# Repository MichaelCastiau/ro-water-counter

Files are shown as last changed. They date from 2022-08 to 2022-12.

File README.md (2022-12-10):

# RO Water Counter
 

This repository contains the source code and hardware schematics for a Reverse Osmosis water counter device, based on an ESP32 module. The device allows for setting an amount of needed liters of water an will swich on/off the RO system automatically. When the amount of liters needed has been reached, the ESP32 module is programmed to interact with a webhook to send a notification to your smartphone.

It interfaces with a high-precision water flow sensor with a K-factor of 20.



## Flashing

```shell
python -m esptool  --port /dev/tty.usbserial-1420 --chip esp32 write_flash 0x00010000 .pio/build/esp32/firmware.bin
```
### Bootloader

The ESP32 requires a second stage bootloader that will read the partition table and boot the corresponding app.
The booloader is located in the `bootloader.bin` file and should be flashed at address 0x1000 in the flash.

```shell
python -m esptool  --port /dev/tty.usbmodem14301 --chip esp32 write_flash 0x1000 bootloader.bin
```

### Partition Table

This project utilises a custom partition table to make enough room for OTA updates.
The partition definitions can be found in `partitions.csv` file. The partition table should be flashed
at address 0x8000 in  the flash after building the project with PlatformIO.

```shell
python -m esptool  --port /dev/tty.usbmodem14301 --chip esp32 write_flash 0x8000 .pio/build/default/partitions.bin
```

### Application

The application itself should be flashed at address 0x10000 (or 0x210000 if using OTA), corresponding to the address defined in the bootloader table.

```shell
python -m esptool  --port /dev/tty.usbmodem14301 --chip esp32 write_flash 0x10000 .pio/build/default/firmware.bin
```

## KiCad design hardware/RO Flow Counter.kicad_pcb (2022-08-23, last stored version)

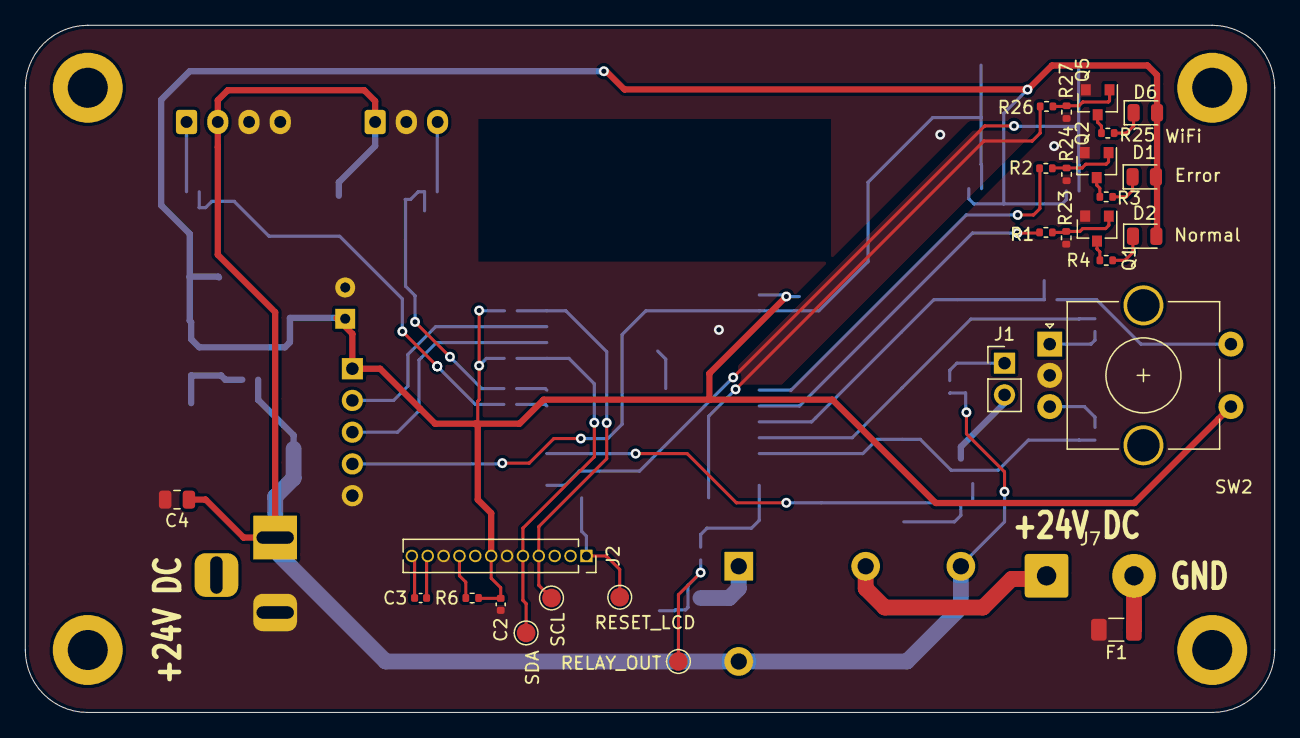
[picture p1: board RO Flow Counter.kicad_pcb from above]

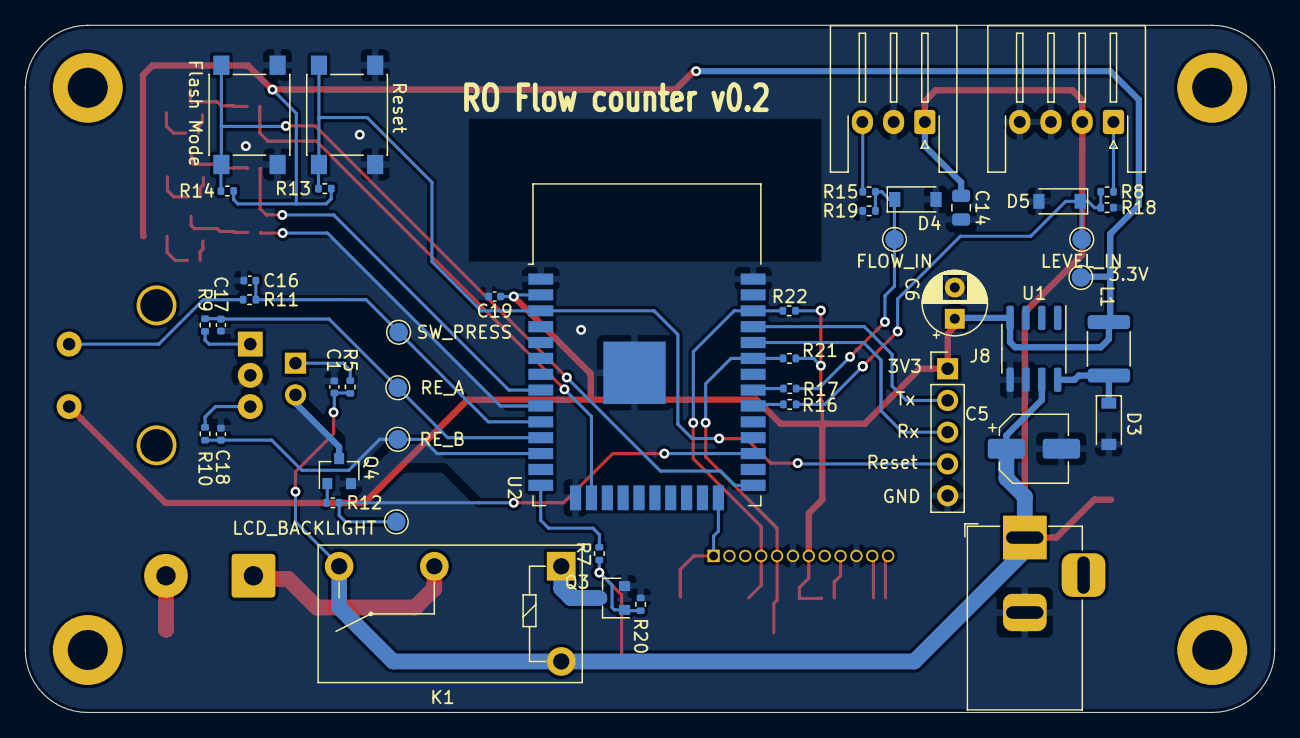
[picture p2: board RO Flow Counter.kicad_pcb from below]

Board: 2 copper layers, 100.0 x 55.0 mm, 79 parts (47 on the bottom side), 47 nets.

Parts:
C1, C2, C3, C16: 100nF; C_0402_1005Metric
C4: 22uF; C_0805_2012Metric
C5: 68uF; CP_Elec_5x5.4
C6: 120uF; CP_Radial_D5.0mm_P2.50mm
C14: 4.7uF; C_0805_2012Metric
C17, C18, C19: 0.1uF; C_0402_1005Metric
D1: Error; LED_0805_2012Metric
D2: Normal Operation; LED_0805_2012Metric
D3: 1N5817; D_SOD-123
D4, D5: 3V3; D_SOD-123
D6: WiFi; LED_0805_2012Metric
F1: 10A; Fuse_1206_3216Metric
H1, H2, H3, H4: MountingHole; MountingHole_3.2mm_M3_DIN965_Pad
J1: LCD Power; PinHeader_1x02_P2.54mm_Vertical
J2: Conn_01x12; PinSocket_1x12_P1.27mm_Vertical
J3: Barrel_Jack; BarrelJack_Horizontal
J5: Flow Meter; JST_XH_S3B-XH-A-1_1x03_P2.50mm_Horizontal
J6: Level Sensor (optional); JST_XH_S4B-XH-A-1_1x04_P2.50mm_Horizontal
J7: Conn_01x02; SolderWire-0.75sqmm_1x02_P7mm_D1.25mm_OD3.5mm
J8: Programming; PinHeader_1x05_P2.54mm_Vertical
K1: G5Q-1A; Relay_SPST_Omron-G5Q-1A
L1: 100uH; L_1812_4532Metric
Q1, Q2, Q3, Q4, Q5: 2N7002E; SOT-23
R1, R2, R7, R9, R10, R11, R12, R16, R17, R26: 1k; R_0402_1005Metric
R3, R25: 154; R_0402_1005Metric
R4: 140; R_0402_1005Metric
R5: 1k4; R_0402_1005Metric
R6, R8, R13, R14, R19, R20, R23, R24, R27: 10k; R_0402_1005Metric
R15, R21, R22: 5k6; R_0402_1005Metric
R18: 1k56; R_0402_1005Metric
SW2: Rotary_Encoder_Switch; RotaryEncoder_Alps_EC11E-Switch_Vertical_H20mm_CircularMoun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
SW3: Reset; SW_Push_1P1T_NO_6x6mm_H9.5mm
SW4: Flash Mode; SW_Push_1P1T_NO_6x6mm_H9.5mm
TP1: 3.3V; TestPoint_Pad_D1.5mm
TP2: SW_PRESS; TestPoint_Pad_D1.5mm
TP3: RE_A; TestPoint_Pad_D1.5mm
TP4: RELAY_OUT; TestPoint_Pad_D1.5mm
TP5: RE_B; TestPoint_Pad_D1.5mm
TP6: SDA; TestPoint_Pad_D1.5mm
TP7: LEVEL_IN; TestPoint_Pad_D1.5mm
TP8: RESET_LCD; TestPoint_Pad_D1.5mm
TP9: FLOW_IN; TestPoint_Pad_D1.5mm
TP11: SCL; TestPoint_Pad_D1.5mm
TP12: LCD_BACKLIGHT; TestPoint_Pad_D1.5mm
U1: LM2594HVM-3.3; SOIC-8_3.9x4.9mm_P1.27mm
U2: ESP32-WROOM-32

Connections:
+3V3: C2.1, C6.1, C19.1, D1.2, D2.2, D6.2, J2.7, J8.1, L1.2, R6.2, R13.1, R14.1, R21.1, R22.1, SW2.S1, TP1.1, U1.4, U2.2
+24V: C1.2, C4.1, C5.1, C14.1, J3.1, J5.1, J6.2, K1.3, K1.5, R5.2, U1.7
/display/BACKLIGHT_LCD: R12.2, TP12.1, U2.27
/display/RESET_DISPLAY: J2.1, TP8.1, U2.24
/display/SCL: J2.4, R22.2, TP11.1, U2.36
/display/SDA: J2.5, R21.2, TP6.1, U2.33
/mcu/ERROR_OUT: R2.1, U2.8
/mcu/FLOW_IN: R17.1, U2.31
/mcu/LED_WIFI: R26.1, U2.16
/mcu/LEVEL_IN: R16.1, U2.30
/mcu/NORMAL_OPERATION_OUT: R1.1, U2.9
/mcu/RELAY_OUT: R7.2, U2.14
/mcu/RE_A: C17.1, R9.2, TP3.1, U2.11
/mcu/RE_B: C18.1, R10.2, TP5.1, U2.12
/mcu/RX: J8.3, U2.34
/mcu/SW_PRESS: C16.1, R11.1, TP2.1, U2.10
/mcu/TX: J8.2, U2.35
/mcu/reset: J8.4, R13.2, SW3.2, U2.3
GND: C1.1, C2.2, C4.2, C5.2, C6.2, C14.2, C16.2, C17.2, C18.2, C19.2, D3.2, D4.2, D5.2, F1.2, J2.6, J2.10, J3.2, J5.2, J6.3, J6.4, J8.5, Q1.2, Q2.2, Q3.2, Q4.2, Q5.2, R18.2, R19.2, R20.1, R23.1, R24.1, R27.1, SW2.C, SW3.1, SW4.2, U1.5, U1.6, U2.1, U2.15, U2.38, U2.39
unnamed: C3.1, J2.12
unnamed: C3.2, J2.11
unnamed: D1.1, R3.1
unnamed: D2.1, R4.1
unnamed: D3.1, L1.1, U1.8
unnamed: D4.1, R15.2, R17.2, R19.1, TP9.1
unnamed: D5.1, R8.2, R16.2, R18.1, TP7.1
unnamed: D6.1, R25.1
unnamed: F1.1, J7.2
unnamed: J1.1, R5.1
unnamed: J1.2, Q4.3
unnamed: J2.9, R6.1
unnamed: J5.3, R15.1
unnamed: J6.1, R8.1
unnamed: J7.1, K1.2
unnamed: K1.1, Q3.3
unnamed: Q1.1, R1.2, R23.2
unnamed: Q1.3, R4.2
unnamed: Q2.1, R2.2, R24.2
unnamed: Q2.3, R3.2
unnamed: Q3.1, R7.1, R20.2, TP4.1
unnamed: Q4.1, R12.1
unnamed: Q5.1, R26.2, R27.2
unnamed: Q5.3, R25.2
unnamed: R9.1, SW2.A
unnamed: R10.1, SW2.B
unnamed: R11.2, SW2.S2
unnamed: R14.2, SW4.1, U2.25

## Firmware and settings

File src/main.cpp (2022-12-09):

#include "config.h"
#include <Arduino.h>
#include <freertos/task.h>
#include "tasks/wifi_task.h"
#include "tasks/default_task.h"
#include "tasks/flow_task.h"
#include "tasks/led_task.h"
#include "tasks/level_task.h"
#include <freertos/event_groups.h>
#include <freertos/queue.h>
#include "models/WSMessage.h"

TaskHandle_t defaultTaskHandle;
TaskHandle_t wifiTaskHandle;
TaskHandle_t flowTaskHandle;
TaskHandle_t ledTaskHandle;
TaskHandle_t levelTaskHandle;

EventGroupHandle_t meterEventGroup;
EventGroupHandle_t ledEventGroup;
EventGroupHandle_t levelEventGroup;
EventGroupHandle_t wiFiEventGroup;

QueueHandle_t litersCounterQueue;
QueueHandle_t toWSQueue;
QueueHandle_t doneLitersQueue;

void GPIO_Init();

void setup()
{
  // put your setup code here, to run once:
  Serial.begin(115200);
  Serial.println("Initialing GPIO pins...");
  GPIO_Init();
  Serial.println("Pins initialised");

  meterEventGroup = xEventGroupCreate();
  ledEventGroup = xEventGroupCreate();
  levelEventGroup = xEventGroupCreate();
  wiFiEventGroup = xEventGroupCreate();

  litersCounterQueue = xQueueCreate(10, sizeof(double));
  doneLitersQueue = xQueueCreate(10, sizeof(double));
  toWSQueue = xQueueCreate(10, sizeof(WSMessage));

  xTaskCreate(StartWiFiTask, "WiFi Task", configMINIMAL_STACK_SIZE + 9000, NULL, 2, &wifiTaskHandle);
  xTaskCreate(StartFlowTask, "Flow Task", configMINIMAL_STACK_SIZE + 3000, NULL, 1, &flowTaskHandle);
  xTaskCreate(StartDefaultTask, "WiFi Task", configMINIMAL_STACK_SIZE + 1024, NULL, 1, &defaultTaskHandle);
  xTaskCreate(StartLEDTask, "LED Task", configMINIMAL_STACK_SIZE + 256, NULL, 3, &ledTaskHandle);
  xTaskCreate(StartLevelTask, "Level Task", configMINIMAL_STACK_SIZE + 256, NULL, 2, &levelTaskHandle);
}

void loop()
{
  delay(500); // Work is done in separate tasks
}

void GPIO_Init()
{
  pinMode(PIN_RESET_LCD, OUTPUT);
  pinMode(PIN_RELAY_OUT, OUTPUT);
  pinMode(PIN_LEVEL_IN, INPUT);

  // Set the default states of all pins
  digitalWrite(PIN_RESET_LCD, LOW);
  digitalWrite(PIN_RELAY_OUT, LOW);
}

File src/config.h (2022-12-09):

#define PIN_RESET_LCD                   2
#define PIN_RELAY_OUT                   12
#define PIN_LCD_BACKLIGHT               16
#define PIN_LEVEL_IN                    18
#define PIN_FLOW_IN                     19
#define RE_PRESS                        25  // rotary encoder press
#define RE_A                            26  // rotary encoder A
#define RE_B                            27  // rotary encoder B
#define LED_ERROR                       32
#define LED_NORMAL                      33
#define LED_WIFI                        13

// Modes
#define MODE_MENU                       (uint8_t)(1 << 1)
#define MODE_RUNNING                    (uint8_t)(1 << 2)
#define MODE_PAUZED                     (uint8_t)(1 << 3)

// Rotary encoder
#define RE_STEPS                        (double) 0.5
#define RE_ROTATE_CLOCKWISE             (1 << 1)
#define RE_ROTATE_COUNTERCLOCKWISE      (1 << 0)

// FLow meter
#define FLOW_PERIOD_MS                   1000
#define RESET_FLOW_METER                 (1 << 0)
#define FLOW_METER_K_FACTOR              (double) 20.0

// LEDs events
#define LED_STATE_NORMAL_RUNNIN          (1 << 0)
#define LED_STATE_NORMAL_PAUZED          (1 << 1)
#define LED_STATE_ERROR                  (1 << 2)
#define LED_STATE_IDLE                   (1 << 3)
#define EN_BACKLIGHT                     (1 << 4)   // Every time event is fired, backlight is enabled for 30s

//LCD
#define BACKLIGHT_MAX                    203
#define BACKLIGHT_IDLE_MS                30000

// WiFi
#define WEBHOOKS_KEY                     (const char*)"bT83HL9K3aVx_YwVMMCmDC"
#define WIFI_CONNECTED                   (1 << 0)

// Water level
#define WATER_TOPPED_OFF                 (1 << 0)

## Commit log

2022-08-15 integrate rotary encoder
2022-08-16 use mode accross entire device
2022-08-16 implement rotary encoder
2022-08-21 fix Q factor, use LEDs
    [config.h, default_task.cpp, flow_task.cpp]
2022-08-21 try to calibrate with flowcount library
2022-08-21 try to calibrate sensor
2022-08-23 add hardware
    [RO Flow Counter-B_Cu.gbr, RO Flow Counter-B_Mask.gbr, RO Flow Counter-B_Paste.gbr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]
2022-08-23 add fabrication outputs
    [RO Flow Counter.kicad_pcb, RO Flow Counter.sch]
2022-08-23 add hardware submodule
    [RO Flow Counter-B_Cu.gbr, RO Flow Counter-B_Mask.gbr, RO Flow Counter-B_Paste.gbr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]
2022-08-23 add hardware as submodule
    [RO Flow Counter-B_Cu.gbr, RO Flow Counter-B_Mask.gbr, RO Flow Counter-B_Paste.gbr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]
2022-08-25 fix: fix counter values not resetting
    [flow_task.cpp]
2022-12-09 remove flow meter
